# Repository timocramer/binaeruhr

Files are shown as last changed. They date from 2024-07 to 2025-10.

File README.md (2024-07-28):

This is a binary pocket watch, made with an atmega48pa. The enclosure is from a cheap pocket watch, mass produced in China and sold via Ebay or Aliexpress.

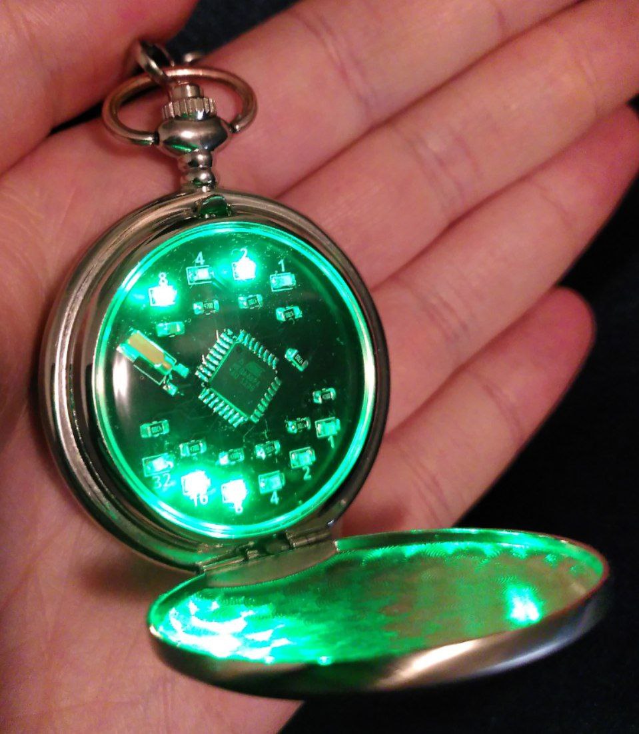
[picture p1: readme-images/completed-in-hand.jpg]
The finished pocket watch in a hand


# how to use the watch

## reading the watch

Open the watch.
The upper four LEDs show the hours in binary, the lower six ones show the minutes. Add the numbers under/over the glowing LEDs to get the current time.
Closing the watch will turn the LEDs off again.

## setting the watch

Press the button for at least 4 seconds (this is called a *long press*). After release the hour LEDs are blinking. Pressing the button for a *short* time will advance the hours. Another long press will enable you to set the minutes in the same way. Pressing the button for a long time in minute setting mode or closing the lid will reset the watch to count and show the time again.

# build your own

Have a look at the [construction manual](construction-manual.md) if you want to build your own.

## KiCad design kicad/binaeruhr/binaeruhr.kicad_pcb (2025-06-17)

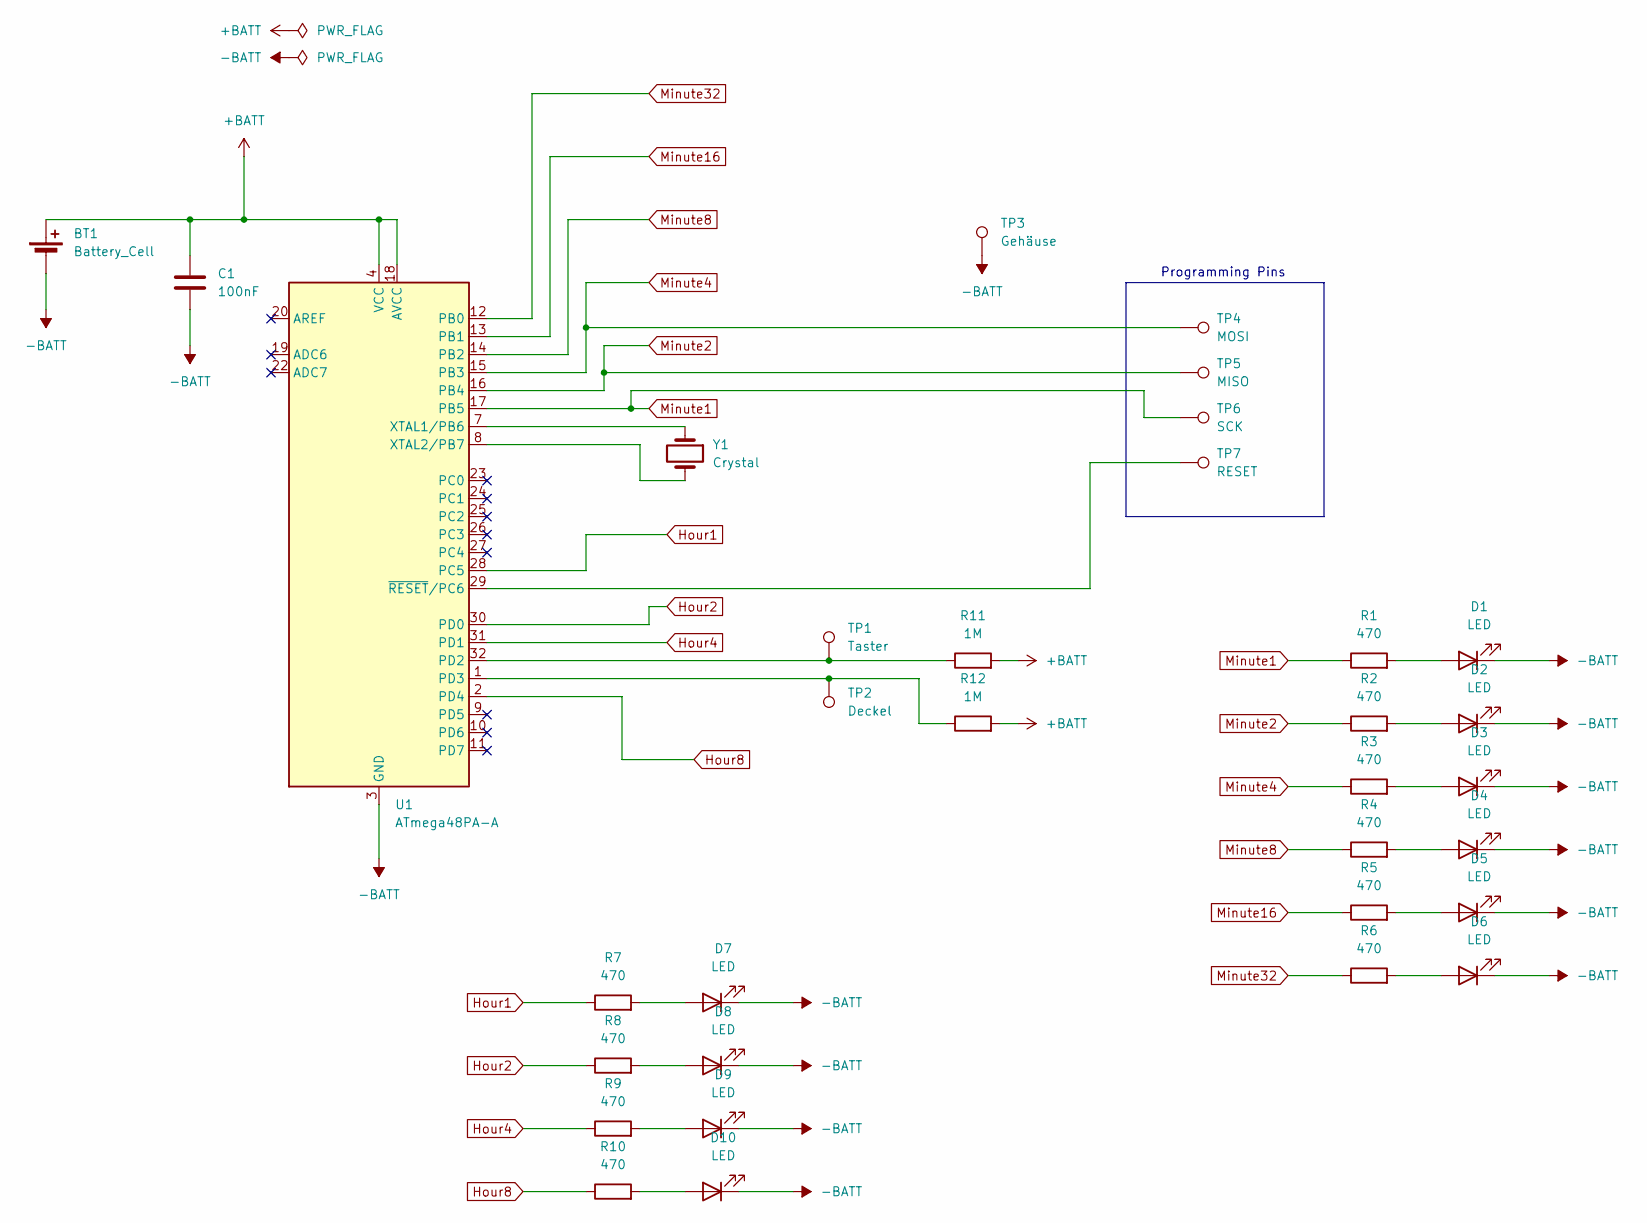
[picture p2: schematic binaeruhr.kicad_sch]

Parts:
BT1: Battery_Cell; BatteryHolder_Keystone_3002_1x2032
C1: 100nF; C_0805_2012Metric_Pad1.18x1.45mm_HandSolder
D1, D2, D3, D4, D5, D6, D7, D8, D9, D10: LED; LED_0805_2012Metric_Pad1.15x1.40mm_HandSolder
R1, R2, R3, R4, R5, R6, R7, R8, R9, R10: 470; R_0805_2012Metric_Pad1.20x1.40mm_HandSolder
R11, R12: 1M; R_0805_2012Metric_Pad1.20x1.40mm_HandSolder
TP1: Taster; TestPoint_Pad_4.0x4.0mm
TP2: Deckel; TestPoint_Pad_4.0x4.0mm
TP3: Gehäuse; TestPoint_Pad_2.0x2.0mm
TP4: MOSI; TestPoint_Pad_1.0x1.0mm
TP5: MISO; TestPoint_Pad_1.0x1.0mm
TP6: SCK; TestPoint_Pad_1.0x1.0mm
TP7: RESET; TestPoint_Pad_1.0x1.0mm
U1: ATmega48PA-A; TQFP-32_7x7mm_P0.8mm
Y1: Crystal; Crystal_SMD_MicroCrystal_MS1V-T1K

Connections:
+BATT: BT1.1 (+), C1.1, R11.2, R12.2, U1.4 (VCC), U1.6 (VCC), U1.18 (AVCC)
-BATT: BT1.2 (-), C1.2, D1.1 (K), D2.1 (K), D3.1 (K), D4.1 (K), D5.1 (K), D6.1 (K), D7.1 (K), D8.1 (K), D9.1 (K), D10.1 (K), TP3.1, U1.3 (GND), U1.5 (GND), U1.21 (GND)
Hour1: R7.1, U1.28 (PC5)
Hour2: R8.1, U1.30 (PD0)
Hour4: R9.1, U1.31 (PD1)
Hour8: R10.1, U1.2 (PD4)
Minute1: R1.1, TP6.1, U1.17 (PB5)
Minute2: R2.1, TP5.1, U1.16 (PB4)
Minute4: R3.1, TP4.1, U1.15 (PB3)
Minute8: R4.1, U1.14 (PB2)
Minute16: R5.1, U1.13 (PB1)
Minute32: R6.1, U1.12 (PB0)
unnamed: D1.2 (A), R1.2
unnamed: D2.2 (A), R2.2
unnamed: D3.2 (A), R3.2
unnamed: D4.2 (A), R4.2
unnamed: D5.2 (A), R5.2
unnamed: D6.2 (A), R6.2
unnamed: D7.2 (A), R7.2
unnamed: D8.2 (A), R8.2
unnamed: D9.2 (A), R9.2
unnamed: D10.2 (A), R10.2
unnamed: R11.1, TP1.1, U1.32 (PD2)
unnamed: R12.1, TP2.1, U1.1 (PD3)
unnamed: U1.7 (XTAL1/PB6), Y1.1
unnamed: U1.8 (XTAL2/PB7), Y1.2
unnamed: TP7.1, U1.29 (~RESET/PC6)

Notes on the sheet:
Programming Pins

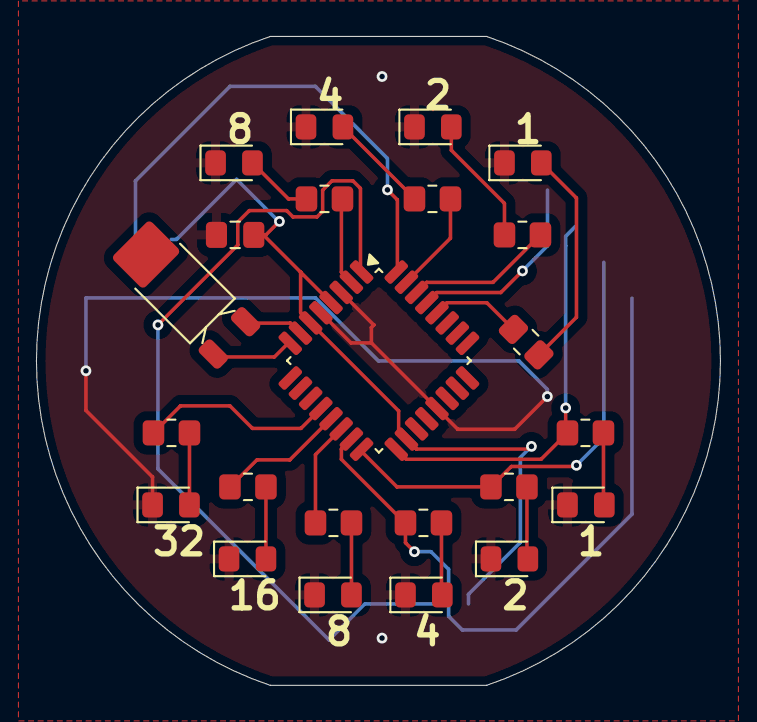
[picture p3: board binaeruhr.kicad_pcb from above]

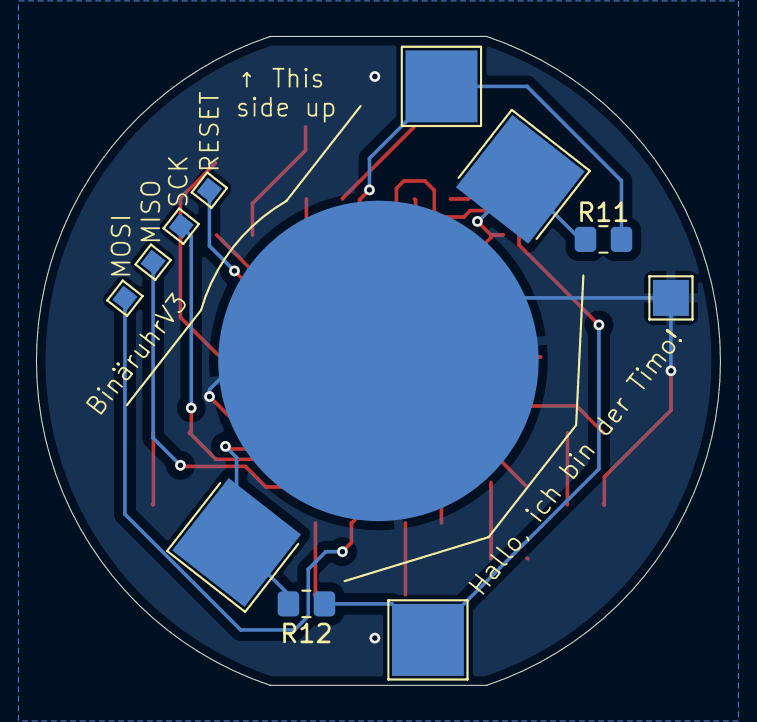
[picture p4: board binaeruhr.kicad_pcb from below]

Board: 2 copper layers, 38.0 x 36.0 mm, 33 parts (10 on the bottom side), 27 nets.

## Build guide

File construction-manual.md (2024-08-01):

# parts

To solder and assemble the pocket watch, you need

- 1x ATmega48PA in TQFP package
- 1x 100nF capacitor 0805
- 10x 0805 LEDs
- 10x 0805 resistors for the LEDs (I use 470Ω)
- 2x 0805 1MΩ resistors
- 1x 32768Hz quartz, 6pF (I use MS1V-T1K)
- 1x SMD battery holder for a CR2032
- 2x pogo pin
- stiff wire that can be soldered to the PCB
- a pocket watch enclosure
- superglue
- USBASP or similar for flashing
- 1x CR2032 battery
- some paper towel or cloth

# assembly

1. Open the pocket watch and remove the face and the plastic bracket. Keep the button and rod for setting the watch.

2. Cut the threaded part of the rod, only keep the part to push the spring down with the button.

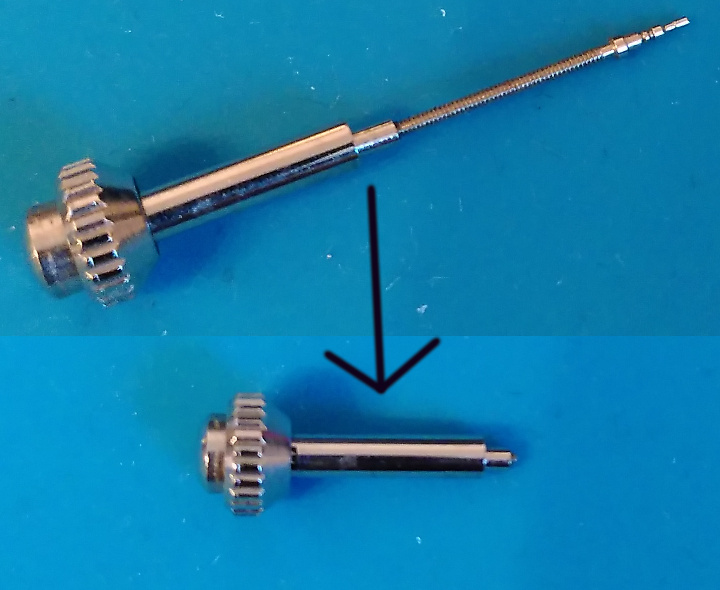
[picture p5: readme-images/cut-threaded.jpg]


3. Use superglue to attach the button to the enclosure. Make sure, the button still can be pressed.

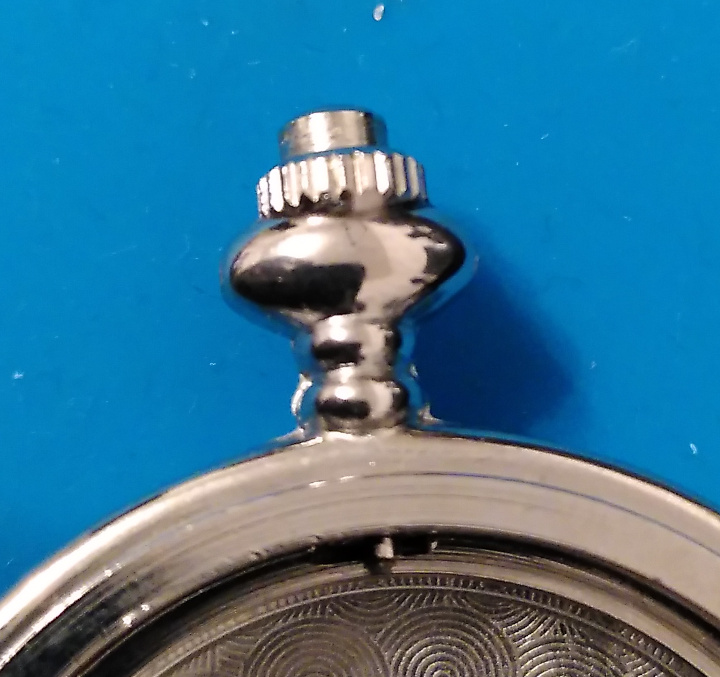
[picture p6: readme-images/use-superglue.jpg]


4. Solder the front side of the PCB.

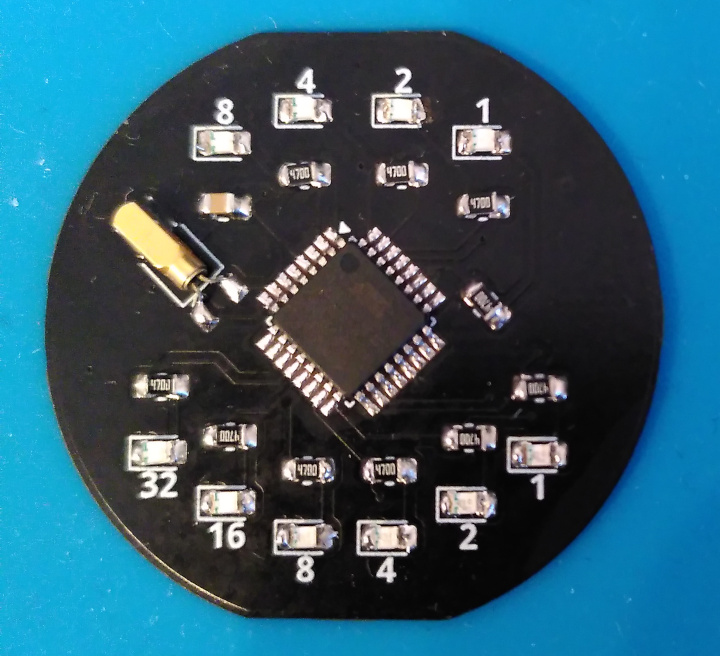
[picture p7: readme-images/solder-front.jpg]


5. Solder the resistors and the battery holder to the back side of the PCB.

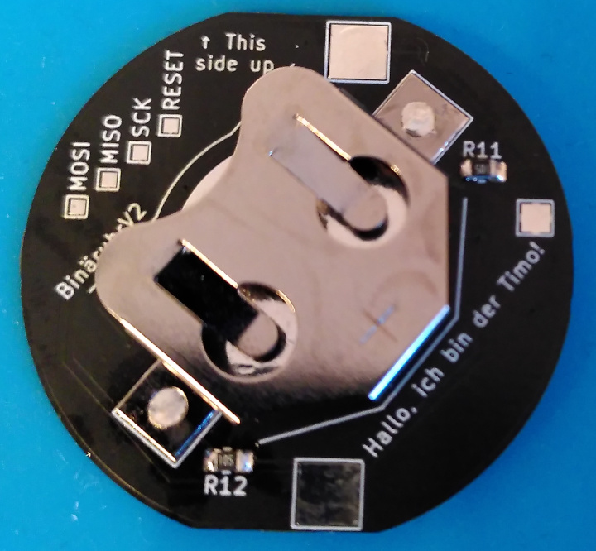
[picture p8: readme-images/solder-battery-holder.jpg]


6. Bend a stiff wire and solder it to the smaller pad on the back side. Make sure it makes contact with the spring in the enclosure.

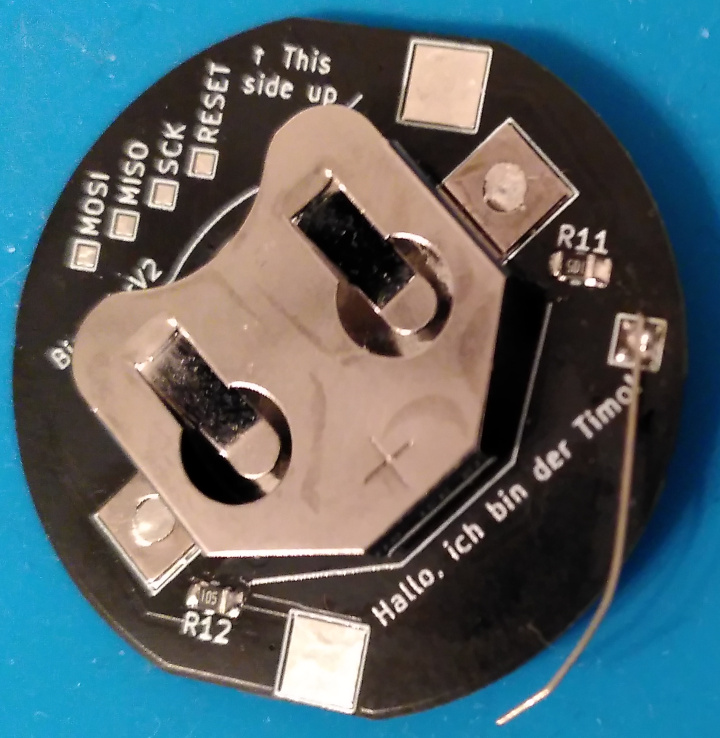
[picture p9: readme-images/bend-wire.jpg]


7. Solder the pogo pins to bigger pads on the back of the PCB. Make sure the upper makes contact when the button is pressed and the lower makes contact when the lid is closed.

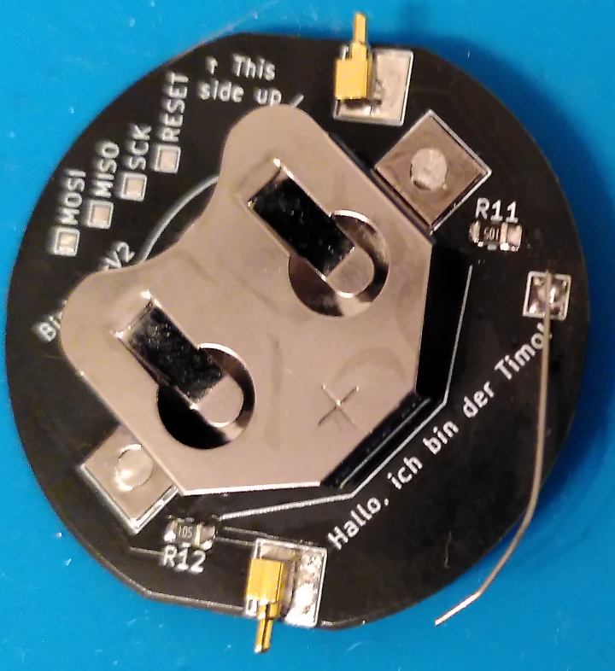
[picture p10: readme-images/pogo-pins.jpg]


8. Flash the software to the microcontroller. I use four Dupont wires with a pin header for the small pads and two clips for power and ground.

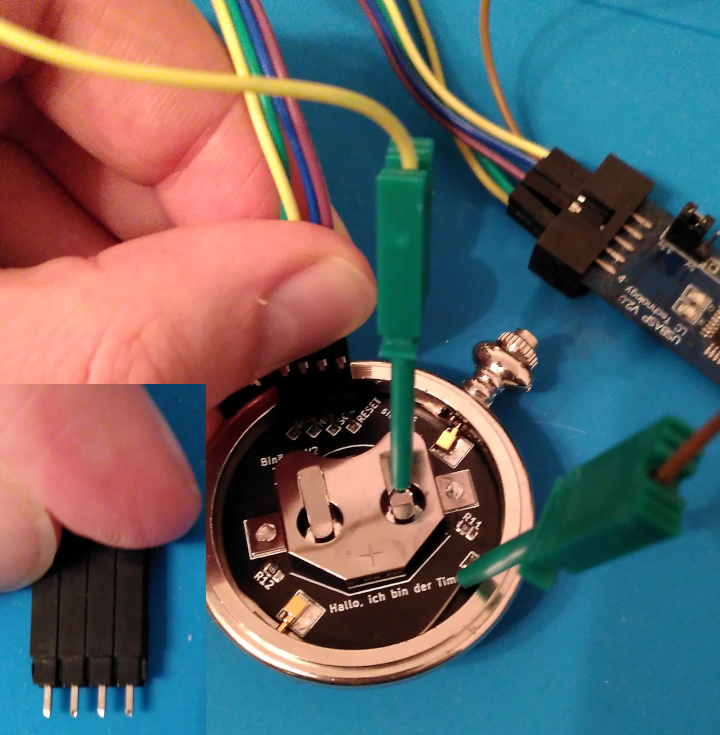
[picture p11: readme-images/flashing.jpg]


9. Insert the battery into the PCB. Insert the PCB into the enclosure. Use some paper towel or cloth to keep the PCB in place in the enclosure. Also the battery should *not* make contact with the back of the enclosure.

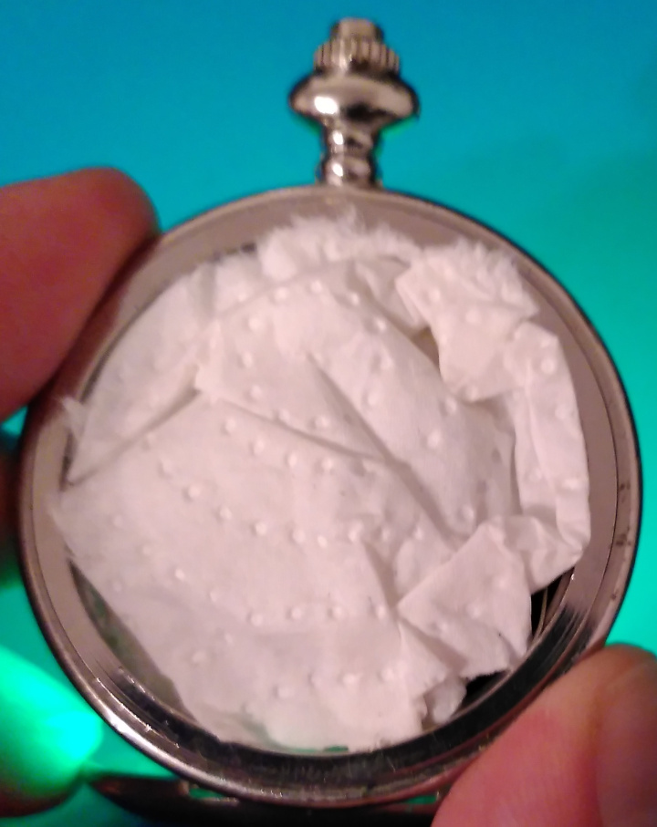
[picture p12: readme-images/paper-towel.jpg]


10. Set time and re-assemble the chain.

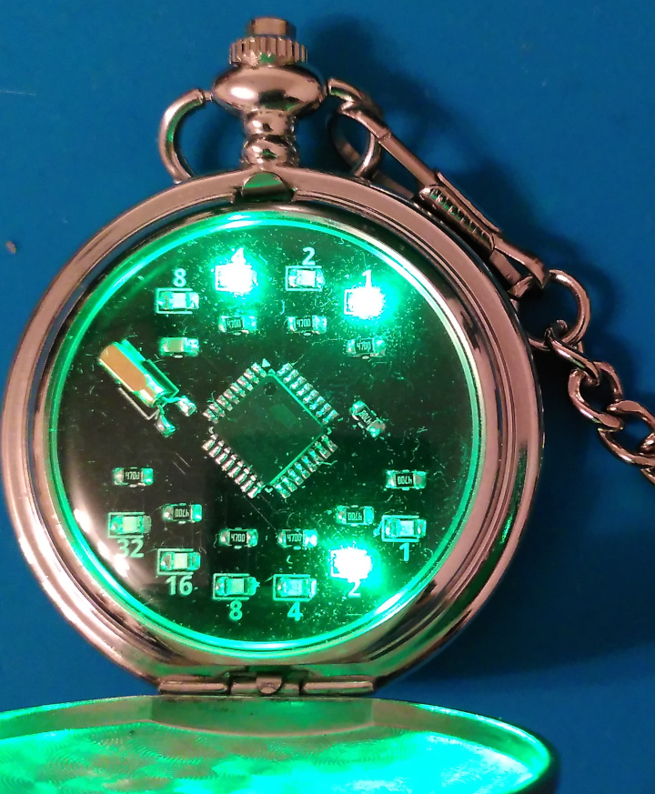
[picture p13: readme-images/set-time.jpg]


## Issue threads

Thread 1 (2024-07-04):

pocket watch opens in time setting mode

timocramer, 2024-07-04:
Sometimes the watch opens and the hours are blinking. Probably the opening button press is detected as a long press.

Maybe this has to do with the interrupt routine of the button pin, as we are leaving it immediately when the lid is closed.

Closed 2024-07-28.

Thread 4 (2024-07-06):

long button press duration is unclear

timocramer, 2024-07-06:
Currently, it is not clear to the user, how long the button must be pressed to get to time setting mode. Best way to switch to time setting mode would be that you have to keep the button pressed until the leds start blinking.

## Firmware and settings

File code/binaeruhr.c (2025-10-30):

#include <stdint.h>

#include <avr/io.h>
#include <avr/interrupt.h>
#include <avr/sleep.h>
#include <util/delay.h>

#include "localtime.h"
#include "led.h"
#include "flash_time.h"

static constexpr uint16_t TIME_SETTING_PRESCALER = 64;
static constexpr uint16_t TIME_COUNTING_PRESCALER = 1024;

static_assert(TIME_COUNTING_PRESCALER >= 128, "TIME_COUNTING_PRESCALER needs to be at least 128");

static constexpr uint16_t QUARTZ_FREQUENCY = 32768;
static constexpr uint16_t TIMER_OVERFLOW_TICKS = 256;

// SECOND_INCREMENT is the number of seconds to add to the time when a timer interrupt occurs.
// Quartz frequency is 32768 Hz and timer has 8 bits, so a timer overflow happens every (prescaler / (32768 / 256)) seconds.
static constexpr uint8_t SECOND_INCREMENT = (uint16_t)TIME_COUNTING_PRESCALER / (QUARTZ_FREQUENCY / TIMER_OVERFLOW_TICKS);

// debug
// static const uint8_t SECOND_INCREMENT = 60;

static volatile struct localtime watch_time = {
    .seconds = 0,
    .hours = 1,
    .minutes = 1,
};

enum state {
    JUST_SHOW_TIME,
    SET_HOURS,
    SET_MINUTES,
};

static volatile enum state watch_state = JUST_SHOW_TIME;
static volatile uint8_t timer_overflows_with_button_pressed = 0;
static volatile bool show_leds_to_set = false;

static void show_time();

static uint8_t current_timer_value();
static uint16_t time_difference_in_ms(uint8_t timer_value_from, uint8_t timer_value_to, uint8_t timer_overflows);
static void set_timer2_prescaler(uint16_t prescaler, bool reset_timer_value);


static void init_lid_pin_interrupt() {
    uint8_t tmp = EICRA;
    // Any logical change on INT1 generates an interrupt request.
    tmp |= _BV(ISC10);
    tmp &= ~_BV(ISC11);
    EICRA = tmp;
    
    EIMSK |= _BV(INT1);
}

static void init_lid_pin() {
    DDRD &= ~_BV(PD3);
    // PORTD |= _BV(PD3); // replaced with external pullup
    init_lid_pin_interrupt();
}

static bool lid_is_open() {
    return !!(PIND & _BV(PD3));
}

static void init_button_pin_interrupt() {
    uint8_t tmp = EICRA;
    // Any logical change on INT0 generates an interrupt request.
    tmp |= _BV(ISC00);
    tmp &= ~_BV(ISC01);
    EICRA = tmp;
    
    EIMSK |= _BV(INT0);
}

static void init_button_pin() {
    DDRD &= ~_BV(PD2);
    // PORTD |= _BV(PD2); // replaced with external pullup
    init_button_pin_interrupt();
}

static bool button_is_down() {
    return !(PIND & _BV(PD2));
}

static void set_time_showing_mode(bool reset_timer_value) {
    watch_state = JUST_SHOW_TIME;
    set_timer2_prescaler(TIME_COUNTING_PRESCALER, reset_timer_value);
}

static void set_hours_setting_mode() {
    watch_state = SET_HOURS;
    set_timer2_prescaler(TIME_SETTING_PRESCALER, true);
}

static void set_minutes_setting_mode() {
    watch_state = SET_MINUTES;
    set_timer2_prescaler(TIME_SETTING_PRESCALER, true);
}

static void lid_closed_action() {
    set_time_showing_mode(false);
    leds_off();
}

static void switch_time_setting_state() {
    switch(watch_state) {
    case JUST_SHOW_TIME:
        set_hours_setting_mode();
        break;
    case SET_HOURS:
        set_minutes_setting_mode();
        break;
    case SET_MINUTES:
        set_time_showing_mode(true);
        if(lid_is_open()) {
            show_time();
        }
        break;
    }
    
    // start time setting modes with the corresponding leds off
    show_leds_to_set = false;
    // reset seconds on every state change
    watch_time.seconds = 0;
}

static void long_press_action() {
    switch_time_setting_state();
}

static uint8_t increment_with_overflow(uint8_t value, uint8_t maxValue, uint8_t minValue) {
    value += 1;
    if(value > maxValue) {
        value = minValue;
    }
    return value;
}

static void time_setting_increment_hours() {
    watch_time.hours = increment_with_overflow(watch_time.hours, 12, 1);
    show_time();
}

static void time_setting_increment_minutes() {
    watch_time.minutes = increment_with_overflow(watch_time.minutes, 59, 0);
    show_time();
}

static void short_press_action() {
    switch(watch_state) {
    case JUST_SHOW_TIME:
        // do intentionally nothing
        break;
    case SET_HOURS:
        time_setting_increment_hours();
        break;
    case SET_MINUTES:
        time_setting_increment_minutes();
        break;
    }
}

static void button_up_action(uint8_t down_timer_value, uint8_t up_timer_value) {
    const uint16_t milliseconds_pressed = time_difference_in_ms(down_timer_value, up_timer_value, timer_overflows_with_button_pressed);
    
    if(milliseconds_pressed < 180) {
        // too short, do nothing
    } else if(milliseconds_pressed < 1000) {
        // short press
        short_press_action();
    } else if(milliseconds_pressed < 4000) {
        // uncanny valley between short and long, do nothing
    } else if(milliseconds_pressed < 10000) {
        // long press
        long_press_action();
    } else {
        // too long, do nothing
    }
}

// interrupt of button pin
ISR(INT0_vect) {
    const bool lid_open = lid_is_open();

    static uint8_t button_down_at = 0;
    if(button_is_down()) {
        button_down_at = current_timer_value();
    } else {
        const uint8_t button_up_at = current_timer_value();
        
        if(lid_open) {
            button_up_action(button_down_at, button_up_at);
        }
        
        // set button_down_at, so that when multiple "up"-interrupts in a row happen,
        // they do not use the same "down"-interrupt tick value
        button_down_at = button_up_at;
        timer_overflows_with_button_pressed = 0;
    }
    
    if(!lid_open) {
        // lid is closed, do nothing and reset every time setting state
        lid_closed_action();
    }
}

// interrupt of lid pin
ISR(INT1_vect) {
    if(lid_is_open()) {
        show_time();
    } else {
        lid_closed_action();
    }
}

static void wait_for_finished_timer_operation() {
    while(ASSR & (_BV(TCN2UB) | _BV(OCR2AUB) | _BV(OCR2BUB) | _BV(TCR2AUB) | _BV(TCR2BUB))) {
        // do intentionally nothing
    }
}

static void timer2_write_zero() {
    OCR2A = 0;
    wait_for_finished_timer_operation();
}

static void timer_overflow_action_in_show_time_mode() {
    watch_time = increment_time(watch_time, SECOND_INCREMENT);
    
    if(lid_is_open()) {
        show_time();
    } else {
        lid_closed_action();
    }
}

static void timer_overflow_action_in_set_hours_mode() {
    if(show_leds_to_set) {
        led_show_hours(watch_time.hours);
    } else {
        led_hours_off();
    }
    led_show_minutes(watch_time.minutes);
    
    show_leds_to_set = !show_leds_to_set;
}


static void timer_overflow_action_in_set_minutes_mode() {
    led_show_hours(watch_time.hours);
    if(show_leds_to_set) {
        led_show_minutes(watch_time.minutes);
    } else {
        led_minutes_off();
    }
    
    show_leds_to_set = !show_leds_to_set;
}

static void timer_overflow_action() {
    switch(watch_state) {
    case JUST_SHOW_TIME:
        timer_overflow_action_in_show_time_mode();
        break;
    case SET_HOURS:
        timer_overflow_action_in_set_hours_mode();
        break;
    case SET_MINUTES:
        timer_overflow_action_in_set_minutes_mode();
        break;
    }
}

ISR(TIMER2_OVF_vect) {
    timer2_write_zero();
    
    timer_overflow_action();
    
    if(button_is_down()) {
        timer_overflows_with_button_pressed += 1;
    } else {
        timer_overflows_with_button_pressed = 0;
    }
}

static void show_time() {
    led_show_time(watch_time.hours, watch_time.minutes);
}

static uint16_t current_timer_prescaler() {
    const uint8_t prescaler_bits = TCCR2B & (_BV(CS22) | _BV(CS21) | _BV(CS20));
    
    switch(prescaler_bits) {
    case (_BV(CS22) | _BV(CS21) | _BV(CS20)):
        return 1024;
    case (_BV(CS22) | _BV(CS21)):
        return 256;
    case (_BV(CS22) | _BV(CS20)):
        return 128;
    case (_BV(CS22)):
        return 64;
    case (_BV(CS21) | _BV(CS20)):
        return 32;
    case (_BV(CS21)):
        return 8;
    case (_BV(CS20)):
        return 1;
    default:
        return 0;
    }
}

// prescaler = 0: no clock source
// prescaler = 1: no prescaling
static void set_timer2_prescaler(uint16_t prescaler, bool reset_timer_value) {
    uint8_t new_prescaler_bits = 0;
    bool timer_register_changed = false;
    
    switch(prescaler) {
    case 0:
        new_prescaler_bits = 0;
        break;
    case 1:
        new_prescaler_bits = _BV(CS20);
        break;
    case 8:
        new_prescaler_bits = _BV(CS21);
        break;
    case 32:
        new_prescaler_bits = _BV(CS21) | _BV(CS20);
        break;
    case 64:
        new_prescaler_bits = _BV(CS22);
        break;
    case 128:
        new_prescaler_bits = _BV(CS22) | _BV(CS20);
        break;
    case 256:
        new_prescaler_bits = _BV(CS22) | _BV(CS21);
        break;
    case 1024:
        new_prescaler_bits = _BV(CS22) | _BV(CS21) | _BV(CS20);
        break;
    default:
        return;
    }
    
    if(reset_timer_value) {
        TCNT2 = 0;
        timer_register_changed = true;
    }
    
    const uint8_t current_register_value = TCCR2B;
    const uint8_t current_prescaler_bits = current_register_value & (_BV(CS22) | _BV(CS21) | _BV(CS20));
    
    if(current_prescaler_bits != new_prescaler_bits) {
        TCCR2B = (current_register_value & ~(_BV(CS22) | _BV(CS21) | _BV(CS20))) | new_prescaler_bits;
        timer_register_changed = true;
    }
    
    if(timer_register_changed) {
        wait_for_finished_timer_operation();
    }
}

static void reset_unused_timer_registers() {
    // the datasheet says after setting async mode, these registers (plus the ones set
    // in set_timer2_prescaler) can be corrupted. so we set them to default
    
    wait_for_finished_timer_operation();
    TCCR2A = 0x00;
    OCR2A = 0x00;
    OCR2B = 0x00;
    wait_for_finished_timer_operation();
}

static void init_timer2(uint16_t prescaler) {
    GTCCR |= _BV(TSM) | _BV(PSRASY);  // Stop timer and reset prescaler
    ASSR |= _BV(AS2); // Set asynchronous mode
    reset_unused_timer_registers();
    set_timer2_prescaler(prescaler, true);
    TIMSK2 |= _BV(TOIE2); // Enable overflow-interrupt
    GTCCR &= ~_BV(TSM); // start timer
}

static uint8_t current_timer_value() {
    return TCNT2;
}

static uint16_t time_difference_in_ms(uint8_t timer_value_from, uint8_t timer_value_to, uint8_t timer_overflows) {
    const uint16_t prescaler = current_timer_prescaler();
    if(prescaler == 0) {
        return 0;
    }
    
    const uint32_t ticks_total = (TIMER_OVERFLOW_TICKS * timer_overflows) + timer_value_to - timer_value_from;
    const uint16_t milliseconds = (ticks_total * 1000) / (QUARTZ_FREQUENCY / prescaler);
    return milliseconds;
}

static void disable_analog_comparator() {
    ACSR |= _BV(ACD);
}

#define STARTUP_BLINK_DELAY_MS 80

static void startup_circle_blink(uint8_t iterations) {
    uint16_t bit_pattern = 1;
    
    for(uint8_t i = 0; i < iterations; ++i) {
        led_show_bit_pattern(bit_pattern);
        
        // draw a full circle, then open it from the back until every led is off.
        // this means, we check if the last led is on, and after that turn every following led off
        if(bit_pattern & (1 << 9)) {
            bit_pattern = (bit_pattern << 1) | 0;
        } else {
            bit_pattern = (bit_pattern << 1) | 1;
        }
        
        _delay_ms(STARTUP_BLINK_DELAY_MS);
    }
}

// this function should draw a clockwise circle starting with hour8, every call shows another LED, so we can see which part is stuck
static void startup_debug_blink() {
    static uint8_t startup_sequence_index = 0;
    
    led_show_bit_pattern((uint16_t)1 << startup_sequence_index);
    
    startup_sequence_index = increment_with_overflow(startup_sequence_index, 9, 0);
    _delay_ms(STARTUP_BLINK_DELAY_MS);
}

static void init_unused_pins() {
    // from the datasheet:
    // If some pins are unused, it is recommended to ensure that these pins have a defined level. [...]
    // The simplest method to ensure a defined level of an unused pin, is to enable the internal pull-up.
    DDRC &= ~(_BV(PC0) | _BV(PC1) | _BV(PC2) | _BV(PC3) | _BV(PC4));
    PORTC |= (_BV(PC0) | _BV(PC1) | _BV(PC2) | _BV(PC3) | _BV(PC4));
    DDRD &= ~(_BV(PD5) | _BV(PD6) | _BV(PD7));
    PORTD |= (_BV(PD5) | _BV(PD6) | _BV(PD7));
}

static void initialize_time_from_eeprom() {
    watch_time = load_time_from_eeprom();
}

int main(void) {
    // pins need to be initialized before we can blink
    init_unused_pins();
    led_init_outputs();
    
    startup_circle_blink(20);
    
    startup_debug_blink();
    init_lid_pin();
    
    startup_debug_blink();
    init_button_pin();
    
    startup_debug_blink();
    disable_analog_comparator();
    
    startup_debug_blink();
    init_timer2(TIME_COUNTING_PRESCALER);
    
    startup_debug_blink();
    initialize_time_from_eeprom();
    
    startup_debug_blink();
    show_time();
    
    sei();
    
    while(1) {
        // dummy write to prevent uninterruptible sleep mode
        timer2_write_zero();
        
        set_sleep_mode(SLEEP_MODE_PWR_SAVE);
        sleep_mode();
    }
    
    return 0;
}

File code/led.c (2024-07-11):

#include "led.h"

#include <avr/io.h>

void led_init_outputs() {
    DDRD |= _BV(PD4); // hour8
    DDRD |= _BV(PD1); // hour4
    DDRD |= _BV(PD0); // hour2
    DDRC |= _BV(PC5); // hour1
    
    DDRB |= _BV(PB0); // minute32
    DDRB |= _BV(PB1); // minute16
    DDRB |= _BV(PB2); // minute8
    DDRB |= _BV(PB3); // minute4
    DDRB |= _BV(PB4); // minute2
    DDRB |= _BV(PB5); // minute1
}

static void hour8_on() {
    PORTD |= _BV(PD4);
}

static void hour8_off() {
    PORTD &= ~_BV(PD4);
}

static void hour4_on() {
    PORTD |= _BV(PD1);
}

static void hour4_off() {
    PORTD &= ~_BV(PD1);
}

static void hour2_on() {
    PORTD |= _BV(PD0);
}

static void hour2_off() {
    PORTD &= ~_BV(PD0);
}

static void hour1_on() {
    PORTC |= _BV(PC5);
}

static void hour1_off() {
    PORTC &= ~_BV(PC5);
}

void led_show_hours(uint8_t hours) {
    if(hours & 8) {
        hour8_on();
    } else {
        hour8_off();
    }
    if(hours & 4) {
        hour4_on();
    } else {
        hour4_off();
    }
    if(hours & 2) {
        hour2_on();
    } else {
        hour2_off();
    }
    if(hours & 1) {
        hour1_on();
    } else {
        hour1_off();
    }
}

static void minute32_on() {
    PORTB |= _BV(PB0);
}

static void minute32_off() {
    PORTB &= ~_BV(PB0);
}

static void minute16_on() {
    PORTB |= _BV(PB1);
}

static void minute16_off() {
    PORTB &= ~_BV(PB1);
}

static void minute8_on() {
    PORTB |= _BV(PB2);
}

static void minute8_off() {
    PORTB &= ~_BV(PB2);
}

static void minute4_on() {
    PORTB |= _BV(PB3);
}

static void minute4_off() {
    PORTB &= ~_BV(PB3);
}

static void minute2_on() {
    PORTB |= _BV(PB4);
}

static void minute2_off() {
    PORTB &= ~_BV(PB4);
}

static void minute1_on() {
    PORTB |= _BV(PB5);
}

static void minute1_off() {
    PORTB &= ~_BV(PB5);
}

void led_show_minutes(uint8_t minutes) {
    if(minutes & 32) {
        minute32_on();
    } else {
        minute32_off();
    }
    if(minutes & 16) {
        minute16_on();
    } else {
        minute16_off();
    }
    if(minutes & 8) {
        minute8_on();
    } else {
        minute8_off();
    }
    if(minutes & 4) {
        minute4_on();
    } else {
        minute4_off();
    }
    if(minutes & 2) {
        minute2_on();
    } else {
        minute2_off();
    }
    if(minutes & 1) {
        minute1_on();
    } else {
        minute1_off();
    }
}

void led_show_time(uint8_t hours, uint8_t minutes) {
    led_show_hours(hours);
    led_show_minutes(minutes);
}

void led_hours_off() {
    hour8_off();
    hour4_off();
    hour2_off();
    hour1_off();
}

void led_minutes_off() {
    minute32_off();
    minute16_off();
    minute8_off();
    minute4_off();
    minute2_off();
    minute1_off();
}

void leds_off() {
    led_hours_off();
    led_minutes_off();
}

void led_show_bit_pattern(uint16_t bit_pattern) {
    if(bit_pattern & 0b0001) {
        hour8_on();
    } else {
        hour8_off();
    }
    if(bit_pattern & 0b0010) {
        hour4_on();
    } else {
        hour4_off();
    }
    if(bit_pattern & 0b0100) {
        hour2_on();
    } else {
        hour2_off();
    }
    if(bit_pattern & 0b1000) {
        hour1_on();
    } else {
        hour1_off();
    }
    bit_pattern >>= 4;
    led_show_minutes(bit_pattern);
}

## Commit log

2024-06-30 use correct function name, we disable the ac not adc
    [binaeruhr.c]
2024-07-01 changes in timer functions
    - fix prescaler 8 bits and add "prescaler" 1
    - more efficient implementation of current_timer_prescaler
    - reset timer conditionally but set timer bits unconditionally
    [binaeruhr.c]
2024-07-02 consistent indentation of switch cases
2024-07-02 use break instead of return so code after the switch is executed (no idea why the compiler was not warning this time)
2024-07-03 use led pins for hour2 and hour4 that are used on the pcb
2024-07-04 reset timer on startup
    [binaeruhr.c]
2024-07-04 add kicad files
    [binaeruhr.kicad_pcb, binaeruhr.kicad_sch]
2024-07-04 add missing text above box
    [binaeruhr.kicad_sch]
2024-07-06 add new function to wait for a finished timer operation
2024-07-06 add function to reset unused timer registers
    [binaeruhr.c]
2024-07-06 set prescaler only when input is different from current value
2024-07-09 give the option to write a distinct time instead of current time
2024-07-11 less repetition in led_show_bit_pattern
2024-07-11 make use of binary constants in led_show_bit_pattern
2024-07-11 add const to button_up_at
2024-07-11 remove leds_on, as it is unused
2024-07-11 move via away from "Hallo, ich bin der Timo!"
    [binaeruhr.kicad_pcb]
2024-07-23 check for last LED, not the the bit after that in startup_circle_blink
2024-07-24 set timer values on every button press, not only when lid is open
    this could fix issue #1
    [binaeruhr.c]
2024-07-28 include in the manual when the battery has to be inserted
2024-09-29 use grouping to turn testing points with closer spacing. This should make Flashing easier
    [binaeruhr.kicad_pcb]
2025-06-17 update kicad files to kicad 9.0
    [binaeruhr.kicad_pcb, binaeruhr.kicad_sch]
